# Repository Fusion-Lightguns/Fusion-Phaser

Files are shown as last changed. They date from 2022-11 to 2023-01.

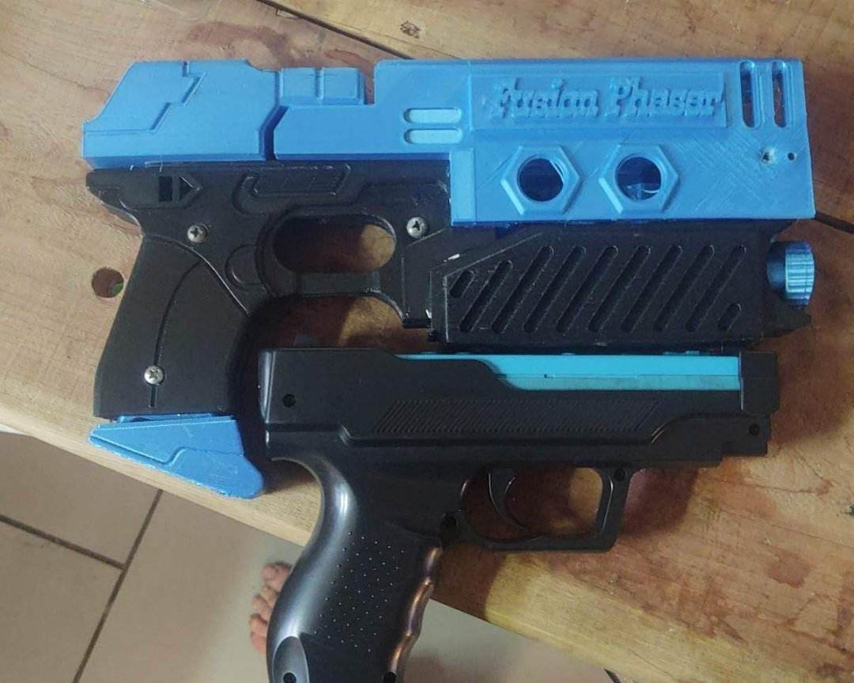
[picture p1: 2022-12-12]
Showcase/Prototype_1/proto_vs_premade wii gun.jpg

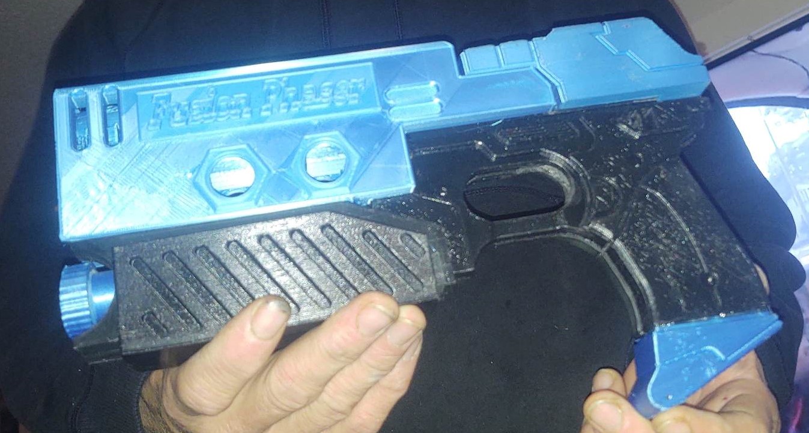
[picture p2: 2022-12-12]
Showcase/Prototype_1/001.jpg

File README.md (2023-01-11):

# Whats this ? 

     A open source Infared Light gun. Built using a microprocesor, a IR Camera (mostly DFRobots), some coding & buttons.
     
# What operating systems Fusion Phaser work on?

     Linux & Windows. 
     
     Tested alright on a XBox One. Need to figure out if I can make better or not worth it.

# Features

     - Easy calibration 
     
     - 7 Buttons on gun
          
     - Open source with DIY instructions & Files. Wanna build yourself do it lol .
     
     - Made by gamers for gamers.

     - 2 different versions of lightgun.
     
        Fusion Phaser & Fusion Phaser Pro
      
     - Trigger pull and power LED
     
     - Joystick on gun for games selection
     
     - Built with Linux/RetroPie in mind . ( Making Setup Scripts)
     
     - Tons of buttons in code if you want add or mod a new gun
     
     - Best button Layout I could figure out for gaming.

# Howd you do this? 

     I used SAMCO and Prow7 IR Lightgun repos on github and modified them to make my own version.
     
# Compatible MicroProcessors

     - Pro Micro
     
     - Itsy Bitsy 32u4 (gotta code it up)

# DIY Files

     - 3D printable Files (STL)
               
               https://github.com/Fusion-Lightguns/Fusion-Phaser/tree/main/DIY/Offical%20Shell/Print/STLs
     
     - Coding Files
     
               https://github.com/Fusion-Lightguns/Fusion-Phaser/tree/main/DIY/Code

# Current Planned For The Future

     - Removable Stock
     
     - DIY Kits
     
     - Premade Lightguns
     
     - Custom PCB for Pro Micro with hookups for everything
     
     - New IR Camera based on Wii Mote Camera . Thiers a few out thier same concept.

# Button Mapping

 On The Lightgun (In Code)-------------Keyboard button
 
     - Trigger ----------------------------Mouse 1
 
     - L Side Button 1 (Start) ------------- Left Alt (mouse 2 if no slide)
 
     - L Side Button 2 (Select) ------------ F4
 
     - R Side Button 1 (A Key) ------------- Tab
 
     - R Side Button 2 (B Key) ------------- Escape
      
     - Slide grip (Reload) ----------------- Mouse 2 (in the works)
 
     - Calibrate (Calibrate) --------------------- Mouse 4 

# Freguently Asked Questions

     - Do I need different code for different type? or for more/less buttons?
        
          No code applys to Phaser & Phaser Pro. Different types have things plug into different spots.
          
     - Can I buy it premade?
     
          Thats the goal in time lol.
          
     - Can I help with development?
     
          If you are a coder please fork and pull request. 
          
          If you wanna donate $$. ATM I dont have anything setup to accept monetary donations.
          
     - Why though? Thiers already lightguns out thier.
     
          I dont like the limit of buttons, attachments and designs on current choices.
          
     - How do  I set it up?
     
          Please See: https://github.com/Fusion-Lightguns/Fusion-Phaser/blob/main/Setup-Phaser.md

# Changelong
      
      - https://github.com/Fusion-Lightguns/Fusion-Phaser/blob/main/Changelog.md

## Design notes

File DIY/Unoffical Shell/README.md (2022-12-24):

# Unoffical Shell DIY. 

# For Coding Instructions See:

      https://github.com/Fusion-Lightguns/Fusion-Phaser/tree/main/DIY/Code/Arduino
      
# Build Instructions Will Vary GREATLY Depending on what shell/gun you are using.

      Heres a basic how to. AGAIN THIS WILL PER GUN.

      - Figure out how many buttons you want.
      
            If just a few see Fusion Volt: https://github.com/Fusion-Lightguns/Fusion-Volt

      - Figure out where you want buttons at.
      
      - Pull apart gun.
      
      - Figure out where you are gonna mount the micro processor at.
      
      - Make sure your buttons will work.
      
      - Figure out where your wiring is going 
      
      - Figure out what "Extras" you want. Example vib motor , power leds that kind of stuff.
            
      - Drill holes for buttons if necessary.
      
      - Mount your micro processor
      
      - Wire it all up 
      
      - Check your connections BEFORE closing gun back up. Plug in to pc/pi and test. 
      
            The calibration ISNT important atm. Just test that buttons & camera are working
      
      - Close Gun back up. 

# We will have some build videos on our youtube 

      https://www.youtube.com/channel/UC4GI1hdy3Z2RpdL8uyicAhw

# See Fusion Volt ( a minimum Fusion Phaser in a lightgun)

      https://github.com/Fusion-Lightguns/Fusion-Volt

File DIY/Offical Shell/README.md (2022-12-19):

# Offical Shell DIY instructions

Click "Build" Folder to build from bought parts

Click "Print" Folder to print then build parts.

# DIY Parts Link:

https://github.com/Fusion-Lightguns/Fusion-Phaser/tree/main/DIY/Parts

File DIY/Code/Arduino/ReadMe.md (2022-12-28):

# DIY Coding Files For Fusion Phaser

1. Install all libraries in Libraries folder to IDE.

Steps 2 & 3 are optional.

2. Grab Fusion-Lightguns-Boards.zip 
  
3. Unzip Fusion-Lightguns-Boards.zip where arduino has packages. in arduin 18.5 it will tell you where under prefences.

        example: C:\Users\yourname\AppData\Local\Arduino15\packages
        
        This will make your gun appear as "Fusion Lightgun" in Windows and Linux

4. See Fusion_Phaser_V_X.XX(newest version) Folder for your board

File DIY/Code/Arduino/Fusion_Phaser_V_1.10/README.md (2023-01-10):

DIY Code for Fusion Phaser

You will need

    - A Pro Micro

    - A PC or computer to use IDE on.

    - Arduino IDE.

    - A cable to hook processor to pc.

Insturctions for use

    - Grab the zip file for your board. Example using a Pro micro, grab FusionPhaser_ProMicro.zip

    - Extract your zip where your Arduino sketches are . If not sure extract somewhere you can find.

    - Move Pin-Button-Layout.txt somewhere you remeber

    - Open up IDE

    - Open the .ino file in IDE . Example open FusionPhaser_ProMicro.ino

    - Plug in your processor.

    - Select port and board in IDE .

    - Verify code is gonna do you good.

    - Burn to micro processor.

    - See Pin-Button-Layout.txt to attch everything to your board.

Thats it follow setup instructions now you got code on board.

https://github.com/Fusion-Lightguns/Fusion-Phaser/blob/main/Setup-Phaser.md

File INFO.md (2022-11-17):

# Whats this ? 

     A Arduino/Arduino clone Light gun.

# What operating systems Fusion Phaser work on?

     Linux & Windows 

# What's different than other Lightguns? 

     - Fusion Phaser is a custom designed gun.
    
     - More buttons that most. Will have a dpad/joystick & 5 buttons, including trigger .

     - Open source codes and designs. Wanna build yourself do it lol .

     - Made by gamers for gamers.

     - Assembled/made & coded in USA.

     - 4 different versions of lightgun. 
          Fusion Phaser, Fusion Phaser Pro & Fusion Phaser Elite.

     - DIY instructions .

     - Setup scripts and code .

     - Built with Linux/RetroPie in mind .

     - Removable Foregrip and attachments .

# How far along is this project ?

     - Named Fusion Phasers 

     - Purchased a DIY kit to see if using them is feasible .

     - Started to code a Teensy LC to act like Arduino .

     - Figuring out which microprocessor to use if not kit.

# What do different types mean ?

     - Fusion Phaser Includes 

         - Lightgun & IR LED setup.

         - Vibration motor 

         - Power LED 

         - Trigger LED (flashes when you pull trigger)

     - Fusion Phaser Pro Includes 

         - Everything from Fusion Phaser. 

         - Solenoid. (For arcade feel) 

         - "Name Plate" Whatever laser burnt on wood and mounted on gun.

     - Fusion Phaser Elite Includes 

         - Everything from Fusion Phaser and Fusion Phaser Pro.

         - Foregrip and all accessories included

# Where can I buy a Fusion Phaser? 

     - Currently not for sale. Still in the works .

# What will Fusion Phaser cost ?

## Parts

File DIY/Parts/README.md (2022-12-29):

# Postioning Camera $25

https://www.dfrobot.com/product-1088.html

A alternative source for a clone of DFRobot

https://www.gotronic.fr/art-camera-ir-de-positionnement-sen0158-22705.htm

Another Alternative China Camera $40 not advised lol ... but its thier 

https://www.aliexpress.us/item/3256804461379218.html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

# Vib Motors $2 a piece

https://amzn.to/3P90VfL

# 16MM Buttons 5 Set

https://amzn.to/3UPP5Zm

# With IR LEDS you have 2 chooses. USB Bar or Loose. 

USB Bar uses wii usb bar with ir leds you need 2 of them. 

Looose uses LED kit or diy leds on power supply and splitter

# USB Bar

https://amzn.to/3BNOr7U

# Loose LED Setup $15

https://www.aliexpress.us/item/3256804395507847.html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

https://www.aliexpress.us/item/3256804336848130.html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

https://www.aliexpress.us/item/3256804336848130.html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

# MicroUSB power supply with switch (optional)

https://amzn.to/3iOo7Ui

# Micro Controllers

Make sure to flash the firmware for your choosen board. 

Arduino Pro Micro

https://amzn.to/3iIQu6m

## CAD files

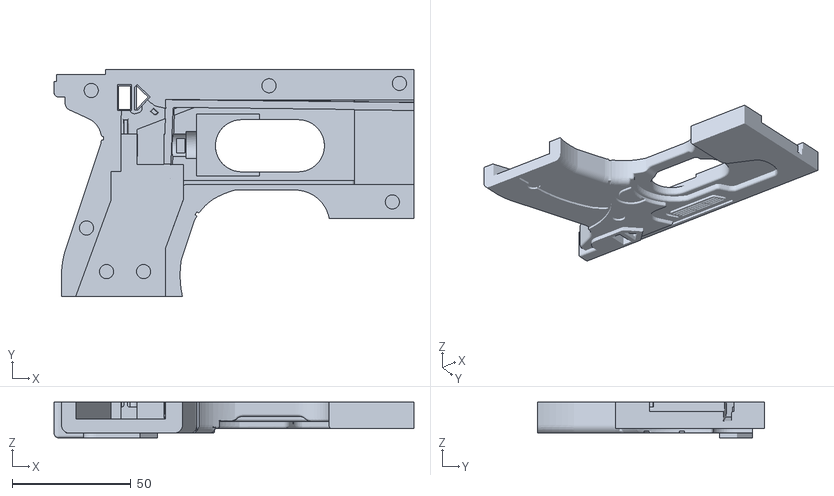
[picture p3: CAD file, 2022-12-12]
DIY/Offical Shell/Print/STLs/Small-STLs/Main-Body-L.stl
151.9 x 95.6 x 15.1

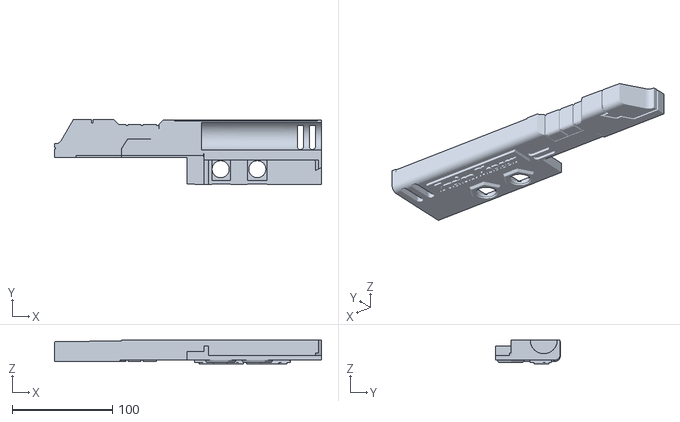
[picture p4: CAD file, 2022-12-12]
DIY/Offical Shell/Print/STLs/Large-STLs/top-left.stl
266.8 x 64.5 x 23.6

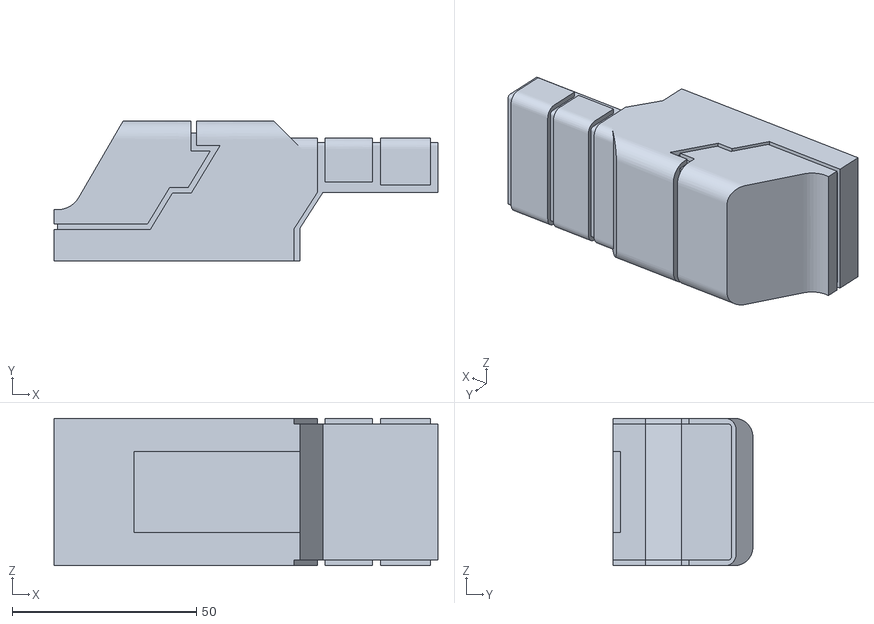
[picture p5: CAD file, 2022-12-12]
DIY/Offical Shell/Print/STLs/Small-STLs/Barrel-Hammer.stl
104.2 x 37.9 x 40.0

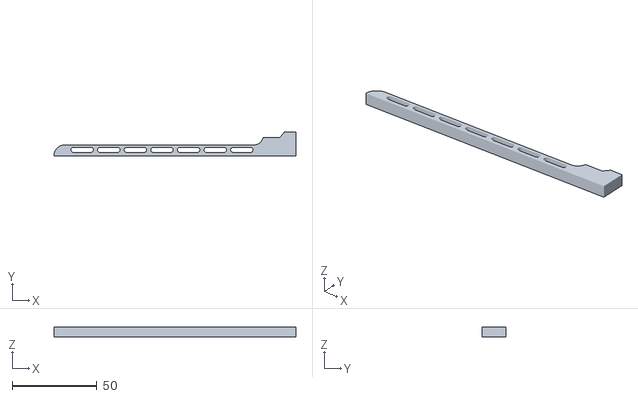
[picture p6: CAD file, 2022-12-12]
DIY/Offical Shell/Print/STLs/Large-STLs/Sight.stl
143.0 x 14.0 x 6.00

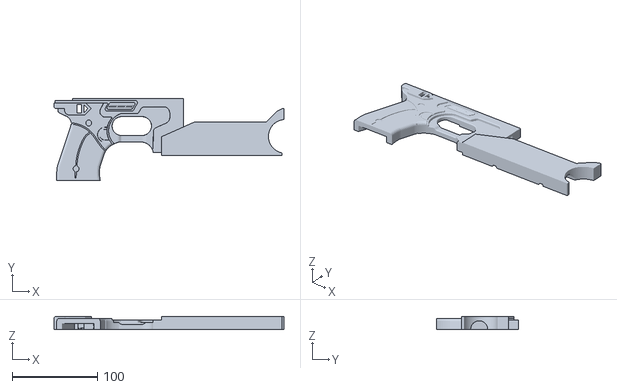
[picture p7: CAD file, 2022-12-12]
DIY/Offical Shell/Print/STLs/Large-STLs/bottom-right.stl
269.3 x 95.6 x 15.2

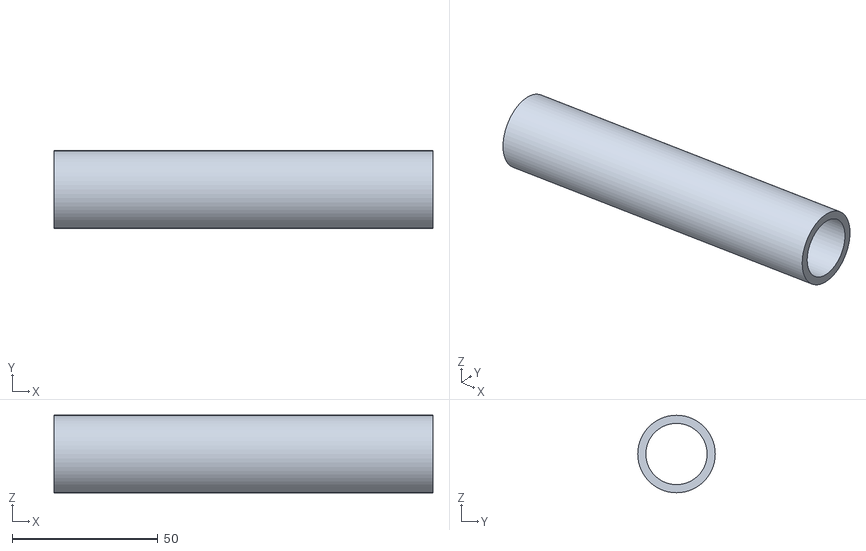
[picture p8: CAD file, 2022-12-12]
DIY/Offical Shell/Print/STLs/Small-STLs/Barrel.stl
130.0 x 26.6 x 26.6

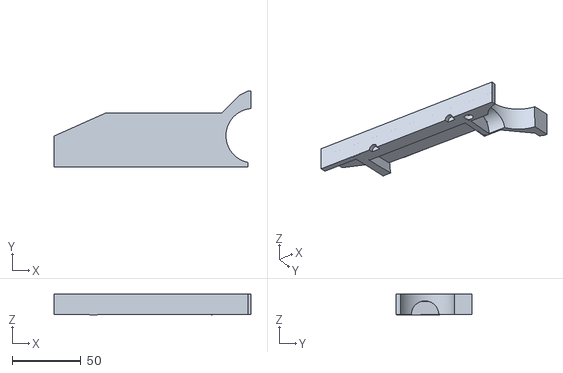
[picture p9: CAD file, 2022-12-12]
DIY/Offical Shell/Print/STLs/Small-STLs/Bottom-Front-R.stl
143.1 x 55.0 x 15.2

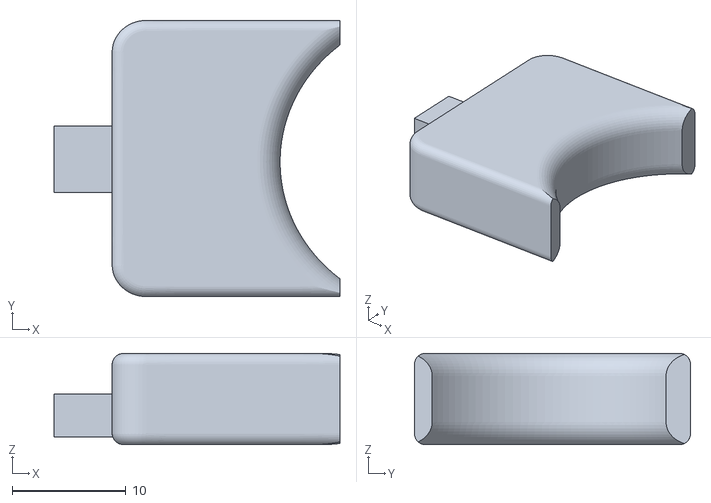
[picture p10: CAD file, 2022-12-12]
DIY/Offical Shell/Print/STLs/Large-STLs/Trigger.stl
25.1 x 24.2 x 8.00

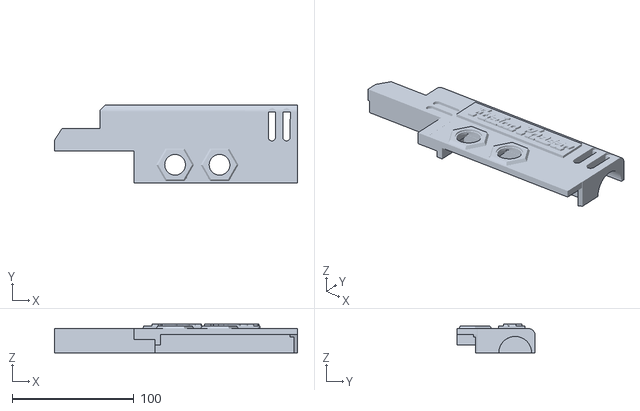
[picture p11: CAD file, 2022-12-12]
DIY/Offical Shell/Print/STLs/Small-STLs/Barrel-Cover-R.stl
200.0 x 64.6 x 23.6

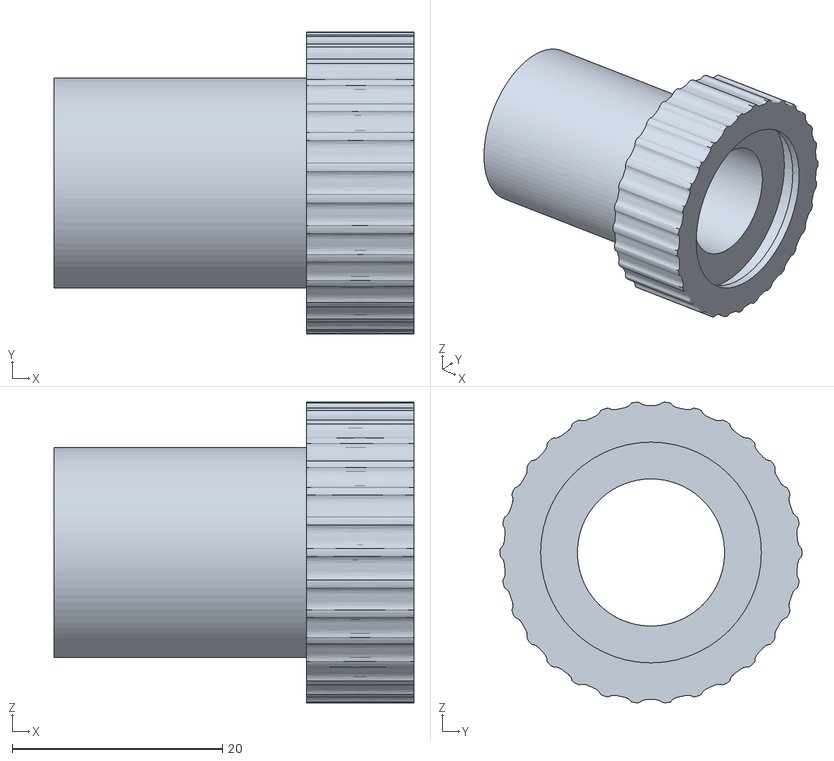
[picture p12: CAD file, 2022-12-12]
DIY/Offical Shell/Print/STLs/Small-STLs/Bottom-Barrell.stl
34.2 x 28.7 x 28.6

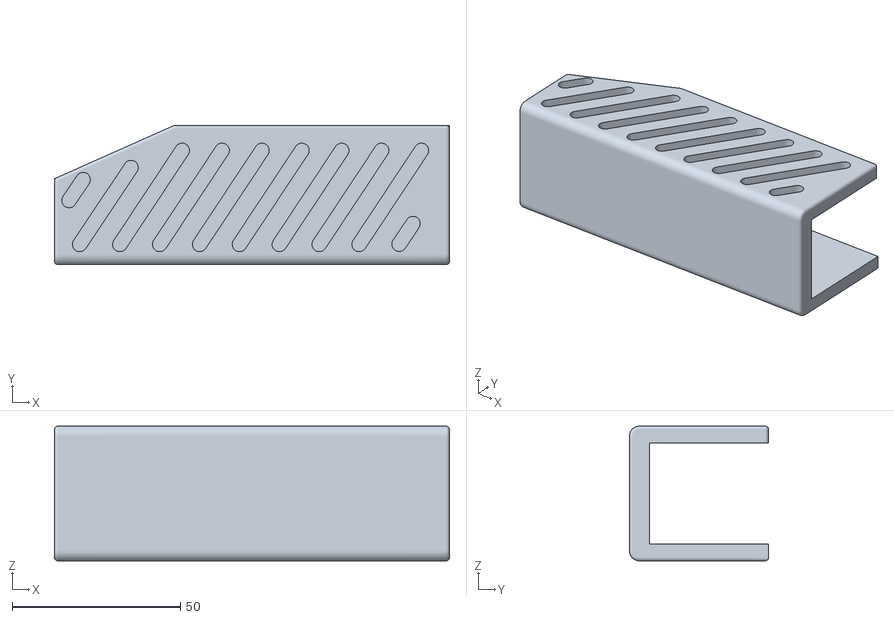
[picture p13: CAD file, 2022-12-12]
DIY/Offical Shell/Print/STLs/Large-STLs/Bottom-Grip.stl
117.2 x 41.3 x 40.0

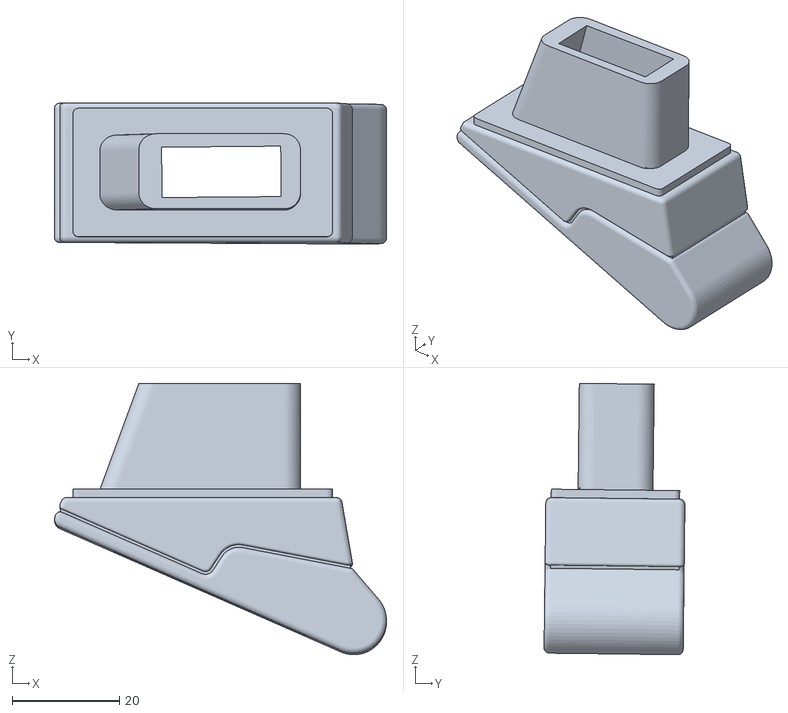
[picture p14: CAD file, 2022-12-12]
DIY/Offical Shell/Print/STLs/Small-STLs/Magazine.stl
62.0 x 26.3 x 50.7

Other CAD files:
DIY/Offical Shell/Print/STLs/Small-STLs/Main-Body-R.stl
DIY/Offical Shell/Print/STLs/Large-STLs/top-right.stl
DIY/Offical Shell/Print/STLs/Large-STLs/bottom-left.stl
DIY/Offical Shell/Print/STLs/Small-STLs/Barrel-Cover-L.stl
DIY/Offical Shell/Print/STLs/Small-STLs/Bottom-Front-L.stl

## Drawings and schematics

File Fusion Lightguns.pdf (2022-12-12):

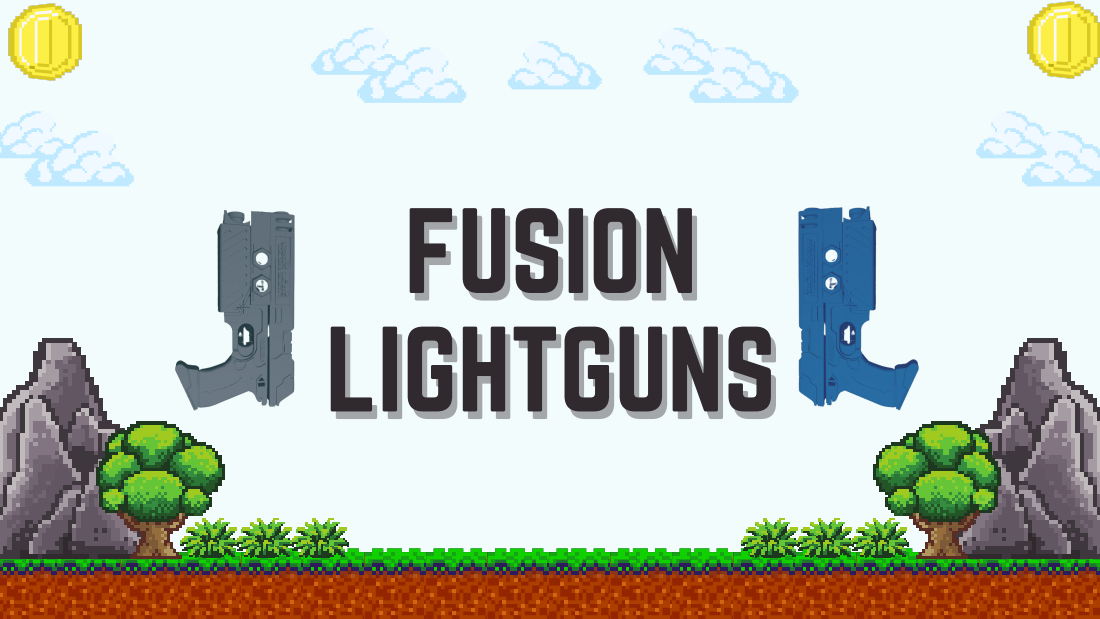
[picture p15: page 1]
FUSION LIGHTGUNS

Love lightguns? Me too!!
So I decided to get into modern lightguns. I really like some but they werent exactly what i was looking for. So I set out to create my own . With the help of a few friends Fusion Lightguns were born.

Fusion
The merging of different elements into a union. Light gun
A device resembling a gun that allows the player of a video game to target a point on the screen.

# IINNTTRROODDUUCCTTIIOONN

OPEN SOURCE

3D PRINTABLE

### 4 BUTTONS & TRIGGER

# FFEEAATTUURREESS

HAND CONTROLLER

### 4 INFARED LEDS

DIY INSTUCTIONS

BUILD IN ANY GUN SHELL

FREE IDE LIBRARIES

ALL SOFTWARE FREE

CALIBRATE BUTTON
ON GUN

CALIBRATE PROGRAM

# SUPPORTED OPERATING SYSTEMS

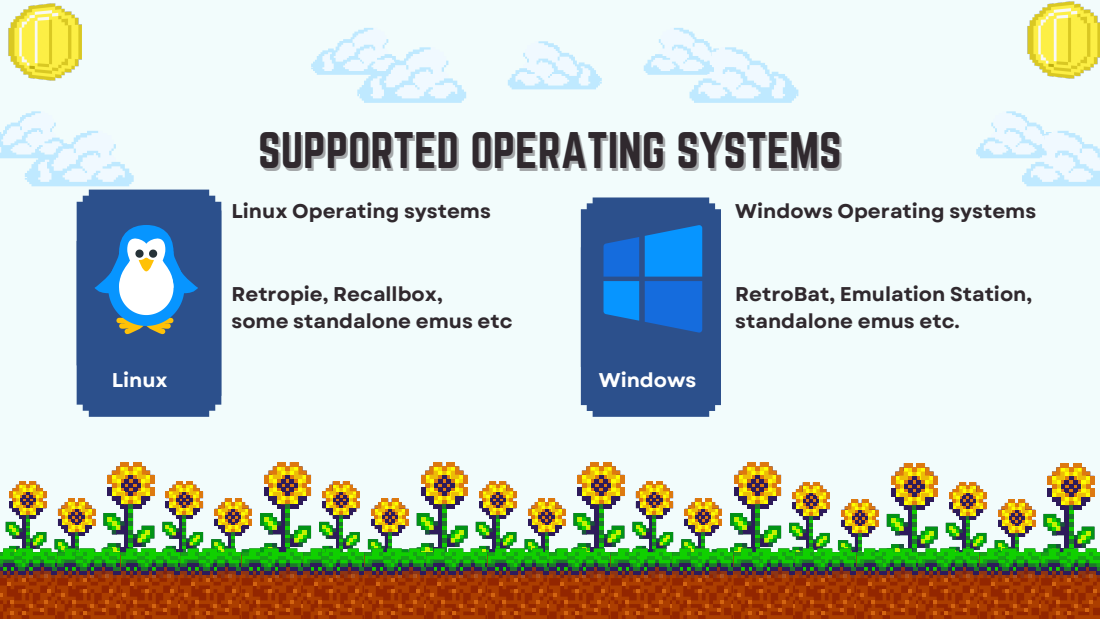
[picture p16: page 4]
Linux; Windows

Linux Operating systems

Windows Operating systems

Retropie, Recallbox,
some standalone emus etc

RetroBat, Emulation Station,
standalone emus etc.

# OUR LIGHTGUNS

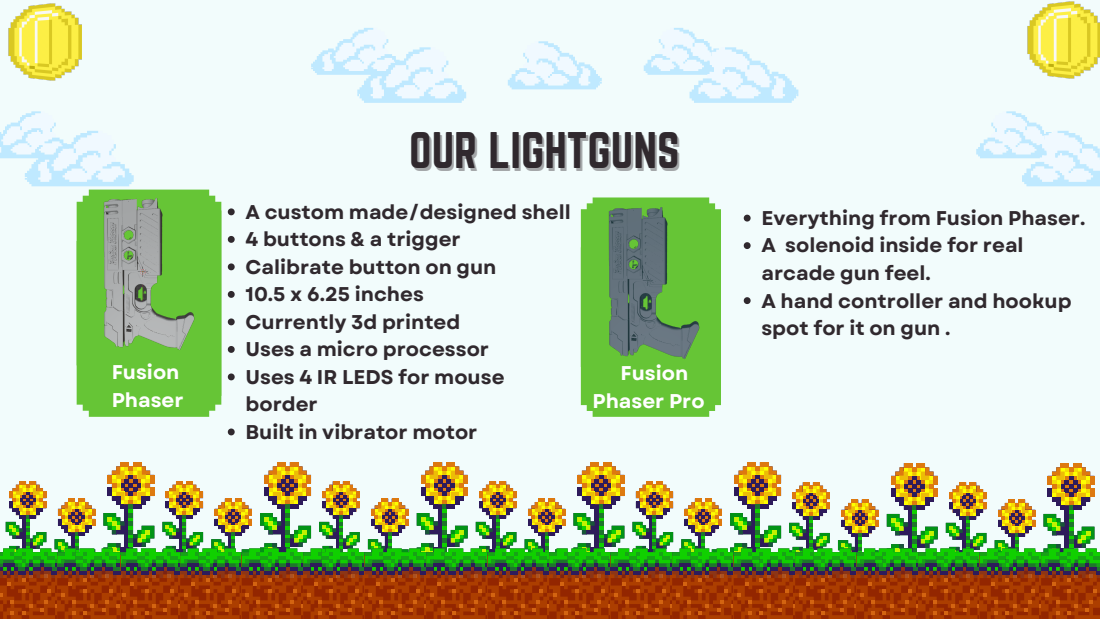
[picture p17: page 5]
Fusion Phaser; Fusion Phaser Pro

A custom made/designed shell
4 buttons & a trigger
Calibrate button on gun
10.5 x 6.25 inches
Currently 3d printed
Uses a micro processor
Uses 4 IR LEDS for mouse
border
Built in vibrator motor

Everything from Fusion Phaser.
A solenoid inside for real
arcade gun feel.
A hand controller and hookup
spot for it on gun .

# SUPPORTED RETRO SYSTEMS

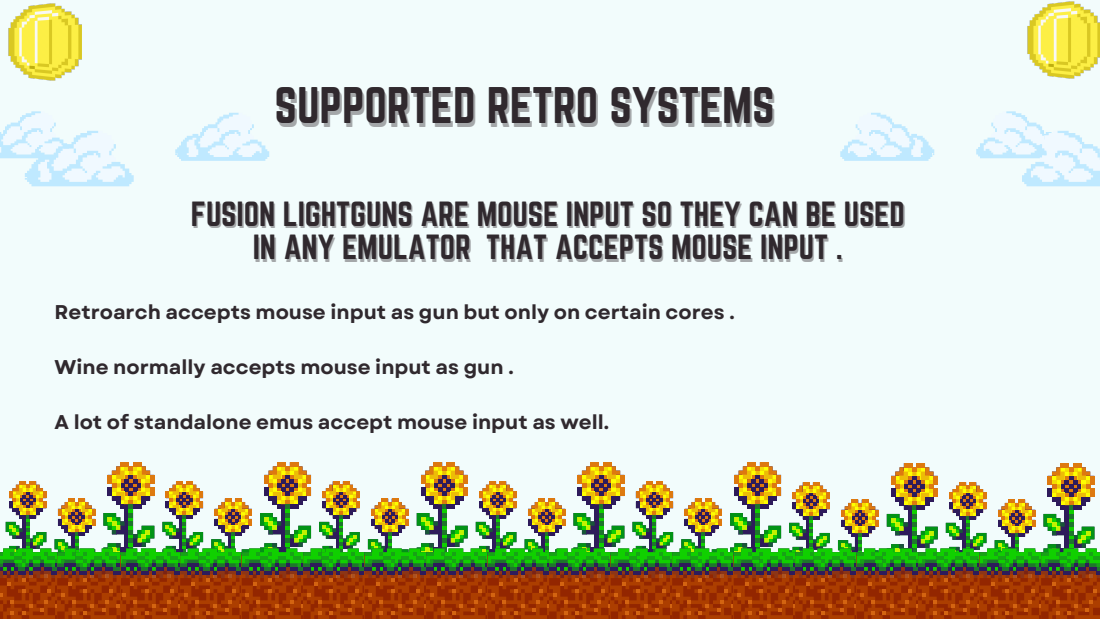
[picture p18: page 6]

FUSION LIGHTGUNS ARE MOUSE INPUT SO THEY CAN BE USED
IN ANY EMULATOR THAT ACCEPTS MOUSE INPUT .

Retroarch accepts mouse input as gun but only on certain cores .

Wine normally accepts mouse input as gun .

A lot of standalone emus accept mouse input as well.

# FREQUENTLY ASKED QUESTIONS

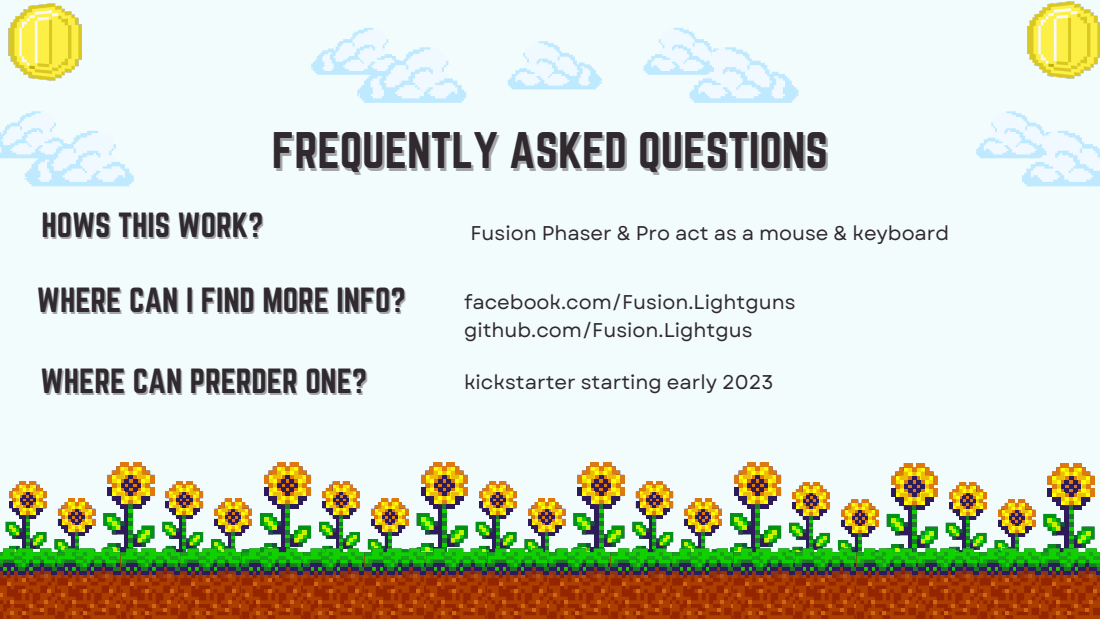
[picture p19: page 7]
WWHHEERREE CCAANN II FFIINNDD MMOORREE IINNFFOO??; facebook.com/Fusion.Lightguns; WWHHEERREE CCAANN PPRREERRDDEERR OONNEE??; kickstarter starting early 2023

HOWS THIS WORK?

Fusion Phaser & Pro act as a mouse & keyboard

github.com/Fusion.Lightgus

# THANKS FOR WATCHING!

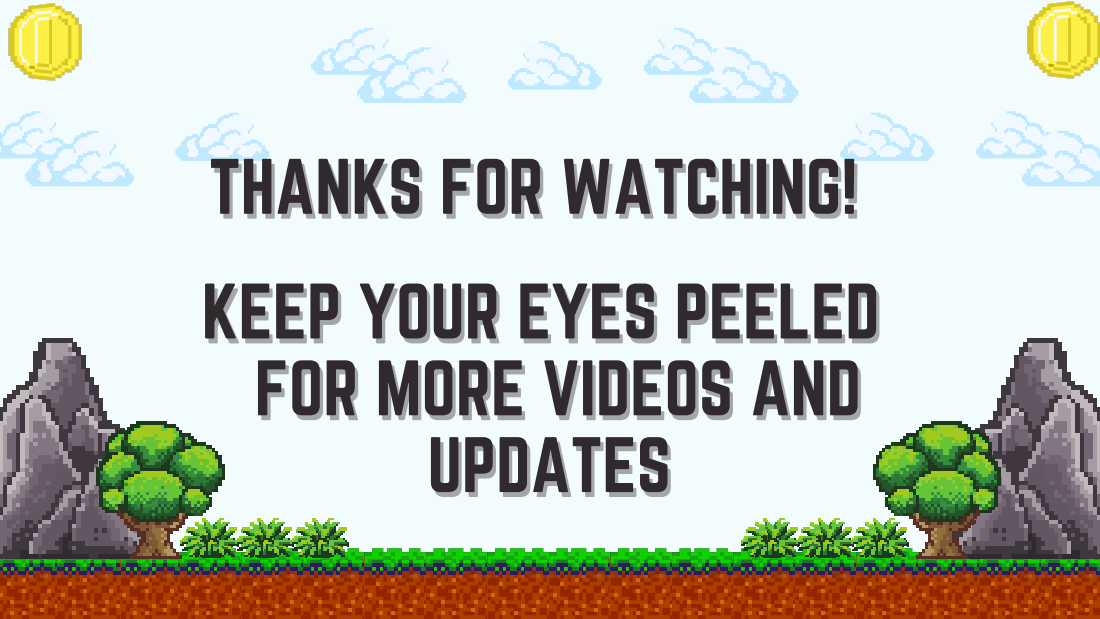
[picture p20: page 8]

KEEP YOUR EYES PEELED
FOR MORE VIDEOS AND
UUPPDDAATTEESS

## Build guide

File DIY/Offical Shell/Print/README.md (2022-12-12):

# Printable files for Fusion Lightgun 

Click STLs Folder for STL files

If using a samll printer use the Small STLs Folder

If using a big printer use the Large STLs Folder

Click Print-Tips.txt for further print help

Click Post-Processing-Tips.txt for detailed after print help

After Printing see below link for build instructions
  
    https://github.com/Fusion-Lightguns/Fusion-Phaser/blob/main/DIY/Offical%20Shell/Build/README.md

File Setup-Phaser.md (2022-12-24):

# Fusion Phaser Setup ------------------- Version 1.00

# LED Setup for Fusion Phaser

    With LED setup you have two choices, USB BAR or Loose.

    USB Bar use IR LEDs in a usb wii bar. NOT RECOMMENDED FOR LARGE TVS

    Loose uses a IR LED Kit or DIY IR LEDS on wires.

# USB Bar Setup

    - Find middle of TV

    - Place USB Bars in center top & bottom of tv/screen.

    - Plug USB Bars into a power supply.

    - Calibrate gun (see below)

    - Enjoy

# Loose LED Setup 

    - PUT LEDs in corners of TV on the top and bottom.
    
    - So one LED set bottom left, one bottom right, one top left, & one top right.

    - Calibrate gun (see below)
    
    - Enjoy

# Calibration

    - Press Reload to enter pause mode.

    - Press a button to select a profile unless you want to calibration the current profile.

    - Pull the Trigger to begin calibration.

    - Shoot the pointer at center of the screen and hold the trigger down for 1/3 of a second while keeping a steady aim.

    - The mouse should lock to the vertical axis. Use the A/B buttons (can be held down) to adjust the mouse vertical range. A will increase and B will decrease. Track the pointer at the top and bottom edges of the screen while adjusting. You can also move your gun centered & click trigger again.

    - Pull the Trigger for horizontal calibration.
    
    - The mouse should lock to the horizontal axis. Use the A/B buttons (can be held down) to adjust the mouse horizontal range. A will increase and B will decrease. Track the pointer at the left and right edges of the screen while adjusting. You can also move your gun centered & click trigger again.

    - Pull the Trigger to finish and return to run mode. Values will apply to the currently selected profile in memory.

    - Recommended: After confirming the calibration is good, enter pause mode and press Start and Select to save the calibration to non-volatile memory.

    Calibration can be cancelled during any step by pressing Reload or Start or Select. The gun will return to pause mode if you cancel the calibration.
    
# Advanced calibration

    - During center calibration, press A to skip this step and proceed to the vertical calibration

    - During vertical calibration, tap Up or Down to manually fine tune the vertical offset

    - During horizontal calibration, tap Left or Right to manually fine tune the horizontal offset

# Saving Settings

    - The calibration data and profile settings can be saved in non-volatile memory. 
      The currently selected profile is saved as the default for when the light gun is plugged in.

    - For ItsyBitsy M0 and M4 boards the external on-board SPI flash memory is used. For Pro Micro & Teensy the EEPROM is used.

# LED Fine Tuning

    - Plug in LEDS

    - Download this github : COMING SOON

    - Extract somewhere 

    - Open Fusion-Gun-Tool Folder

    - Open LED-Fine-Tune.mp4 (MAKE SURE THAT IT FULLSCREEN . YES THE WHOLE SCREEN)

    - Follow Video instructions.

# Operation

    - The light gun operates as a mouse until the button/combination is pressed to enter pause mode. 
      The Arduino serial monitor (or any serial terminal) can be used to see information while the gun is paused and during the calibration procedure.

    - Note that the buttons in pause mode (and to enter pause mode) activate when the last button of the combination releases. 
      This is used to detect and differentiate button combinations vs a single button press.

    - The mouse position updates at 209Hz so it is extremely responsive.

# Run modes

The gun has the following modes of operation:

    - Normal - The mouse position updates from each frame from the IR positioning camera (no averaging)

    - Averaging - The position is calculated from a 2 frame moving average (current + previous position)

    - Averaging2 - The position is calculated from a weighted average of the current frame and 2 previous frames

    - Processing - Test mode for use with the Processing sketch (this mode is prevented from being assigned to a profile)

    - The averaging modes are subtle but do reduce the motion jitter a bit without adding much if any noticeable lag.

# Processing mode

    - The Processing mode is intended for use with the SAMCO Processing sketch. Download Processing from processing.org and find the 4IR Processing sketch from the SAMCO project. The Processing sketch lets you visually see the IR points as seen by the camera. This is very useful aligning the camera when building your light gun and for testing that the camera tracks all 4 points properly. I suppose if you don't want to install Processing then you can just open your favourite serial terminal program and watch the numbers scroll by.

# IR camera sensitivity

    - The IR camera sensitivity can be adjusted. It is recommended to adjust the sensitivity as high as possible. If the IR sensitivity is too low then the pointer precision can suffer. However, too high of a sensitivity can cause the camera to pick up unwanted reflections that will cause the pointer to jump around. It is impossible to know which setting will work best since it is dependent on the specific setup. It depends on how bright the IR emitters are, the distance, camera lens, and if shiny surfaces may cause reflections.

    - A sign that the IR sensitivity is too low is if the pointer moves in noticeable coarse steps, as if it has a low resolution to it. If you have the sensitivity level set to max and you notice this then the IR emitters may not be bright enough.

    - A sign that the IR sensitivity is too high is if the pointer jumps around erratically. If this happens only while aiming at certain areas of the screen then this is a good indication a reflection is being detected by the camera. If the sensitivity is at max, step it down to high or minimum. Obviously the best solution is to eliminate the reflective surface. The Processing sketch can help daignose this problem since it will visually display the 4 IR points.

# Profiles

    - The sketch is configured with 8 profiles available. Each profile has its own calibration data, run mode, and IR camera sensitivity settings. Each profile can be selected from pause mode by assigning a unique button or combination.

# Default Buttons

    - Trigger: Left mouse button

    - A: Right mouse button

    - B: Middle mouse button

    - Start: Enter Key

    - Select: Escape Key 

    - Up/Down/Left/Right: Keyboard arrow keys
    
    - Reload: Enter pause mode

    - Pedal: Mouse button 2

# Default Buttons in Pause mode

    - A, B, Start, Select, Up, Down, Left, Right: select a profile

    - Start + Down: Normal gun mode (averaging disabled)

    - Start + Up: Normal gun with averaging, switch between the 2 averaging modes (use serial monitor to see the setting)

    - Start + A: Processing mode for use with the Processing sketch

    - B + Down: Decrease IR camera sensitivity (use serial monitor to see the setting)

    - B + Up: Increase IR camera sensitivity (use serial monitor to see the setting)

    - Reload: Exit pause mode

    - Trigger: Begin calibration

    - Start + Select: save settings to non-volatile memory (EEPROM or Flash depending on the board configuration)

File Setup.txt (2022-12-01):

---Fusion Phaser
------------------------------------------------
--LED Setup 
1. Unwrap LEDS and figure out wher e your gonna plug in 
2. Mount LEDS in a cross ponts shape. Top of TV in center, left of TV in center and so on.
3. For further LED setup/calbration see Step 6 in Software Setup below

--Software Setup
1. Plug Gun into Pi/PC

2. Extract Fusion-Lightguns.zip

3. For quick calibration (maybe well see)
- press calibration on gun
- shoot the following spots on screen IN ORDER. 
		Top Left, Top Right, Bottom Right, Bottom Left 

4. Advanced Calibration
- For windows follow 3a
- For Linux use 3b

4a. Windows
- Plug in a keyboard
- Plug in Fusion Phaser
- Open \Fusion-Lightguns\Software\Fusion-Guns-Tool\Fusion-Guns-Tool.exe
- Click on Calibrate 
- Follow on screen instructions

4b. Linux/Pi
- Plug in a keyboard
- Plug in Fusion Phaser
- Install Wine to run windows program. Linux program work in progress
- Open \Fusion-Lightguns\Software\Fusion-Guns-Tool\Fusion-Guns-Tool.exe
- Click on Calibrate 
- Follow on screen instructions

5. Click Save Calibration

6. Click on LED Fine Tune (6-8 optional)

7. Check out on screen LED Guide lines 

8. Move LEDS to match Guide Lines 

9. Close Fusion-Guns-Tool

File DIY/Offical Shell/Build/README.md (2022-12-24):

# Build Instructions For Fusion Phaser

- COMING SOON

# Now you need to setup your Gun

Please see:

https://github.com/Fusion-Lightguns/Fusion-Phaser/blob/main/Setup-Phaser.md

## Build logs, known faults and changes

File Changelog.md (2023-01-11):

#  Version 1.00 12/2/22

     - Named Fusion Phasers 

     - Purchased a DIY kit to reverse engineer and learn.
     
     - Finished 3D design of sides of Lightgun
     
     - Built a gun from DIY ki. It was as i epected mostly
     
     - Ordered all basic parts today. Will be begin testing when they arrive
     
     - Decided to use Pi Pico as "Brains" 
     
     - Figured out almost everything needed
     
#  12/10/22

     - Started to build a kickstarter for Fusion Phaser 
     
     - Switched on gun dpad to a wii nunchuck hookup. 
     
     - Added buttons on each side . 2 buttons on each side plus trigger = 5 buttona in total
     
# 12/10/22
     
          - I cant get Pico Pi to work in Arduino IDE. Porbably gonan switch to Arduino Pro 32u4
          
          - Test gun is almost complete.

# 12/17/22

     - Prototype gun finished printing soooo cool . 
     
     - Got a few Pro Micros 32u4 to test on . 
     
     - Ordered a Itsty Bitsty 32u4 5V

     - So far cursor stuck in top left corner lol. (Will work it out)
     
     - Uploaded my ino files to thiss github. WORK IN PROGRESS

# Version 1.02 12/21/22

    - Got a working prototype of Fusion Volt.
    
    - Tested all extra code and buttons for Phaser. Was fine. 
    
    - Making avaible for multiple boards. Currently Pro Micro 32u4 5V & Itsty Bitsy 32u4
    
    - Ordered stuff to capture videos
    
    - Made more progress on kickstarter . ( Waiting till really ready to launch)
    
# Version 1.03 12/23/22

    - Found some awesome enchancements we are gonna use. https://github.com/Prow7/ir-light-gun
    
Prow7 Enhancements

     - Increased precision for maths and mouse pointer position

     - Glitch-free DFRobot positioning (DFRobotIRPositionEx library)

     - IR camera sensitivity adjustment (DFRobotIRPositionEx library)

     - Faster IIC clock option for IR camera (DFRobotIRPositionEx library)

     - Optional averaging modes can be enabled to slightly reduce mouse position jitter

     - Enhanced button debouncing and handling (LightgunButtons library)

     - Modified AbsMouse to be a 5 button device (AbsMouse5 library)

     - Multiple calibration profiles

     - Save settings and calibration profiles to flash memory (SAMD) or EEPROM (ATmega32U4)
     
     - Built in Processing mode for use with the SAMCO Processing sketch

# 12/27/22

     - Changed buttons to make more retropie and gaming freindly.
     
     - Escape, Enter, F4, & Alt mapped now. Instead of extra mouse buttons. 
     
     - Renamed Reload to Calibrate in Code.
     
     - Renamed Pedal to Reload in Code.
     
     - Tested on two pro micro same time worked fine 
     
     - Figured out how to make leonardo appear as Fusion Phaser.
     
     - Nunchuck hooked removed for now . Will have a hand controller custom made with dpad and 2 buttons. 
     
     - Stable tested first release now on github.

# Version 1.10 1/10/22

     - Removed dpad from code
     
     - Added Joystick to code
     
     - Made code simplier
     
     - Added  X, Hotkey, Y, and Coin buttons to code 
     
     - Finalized button mapping
